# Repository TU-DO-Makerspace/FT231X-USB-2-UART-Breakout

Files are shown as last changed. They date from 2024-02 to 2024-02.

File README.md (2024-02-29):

# FT231X USB 2 UART Breakout

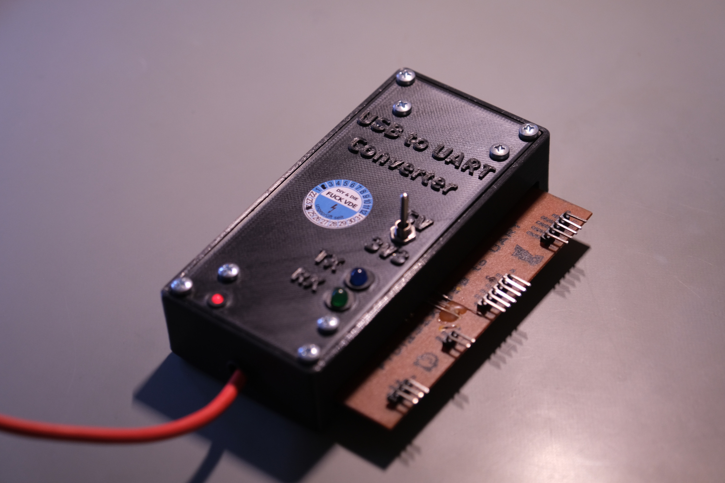
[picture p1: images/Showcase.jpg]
Showcase


This repository features a USB 2 UART converter/breakout board built on the FTDI FT231X IC. Although numerous affordable USB to UART converters are readily available on the market, this particular one was designed around a spare FT231X IC soldered to a SMD break-out adapter we had in our lab. Figured we'd make use of it then! The PCB was designed with a single-board layout in consideration, as we etched the PCB oursevles.

We don't really expect anyone to use this design, but we're making it available for archival purposes in case it breaks down some day or someone is simply curious about the design. However, if you do happen to find it useful, that's pretty awesome too!

## Schematic

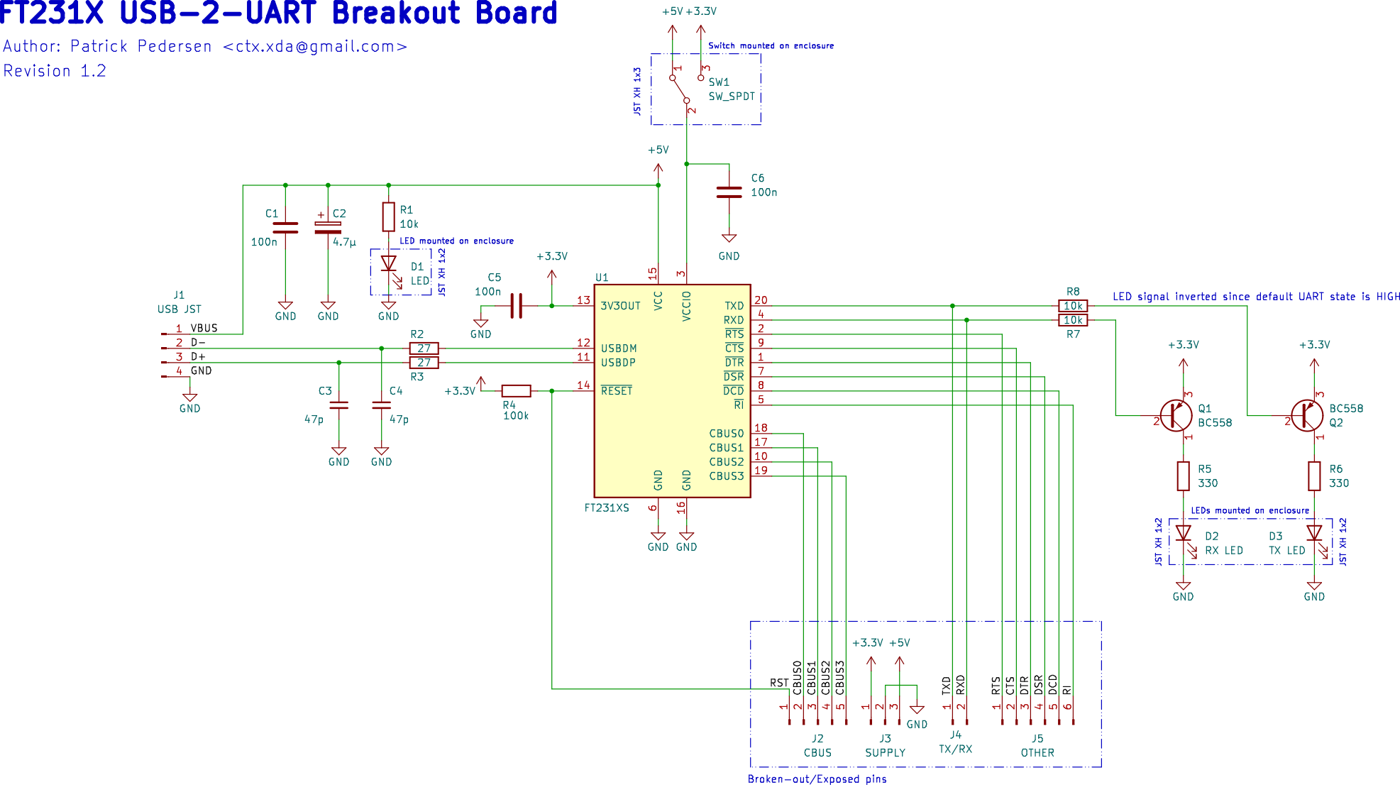
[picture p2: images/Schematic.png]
Schematic


The schematic pretty much provides the bare minimum to use the FT231X IC as a USB to UART converter. Some notable features include:

- A switch to switch between 3.3V and 5V logic levels
- LEDs to indicate power and data transmission
- Exposed supply, RX, TX, RTS, CTS, DTR, DSR, DCD, and RI pins
- Exposed CBUS pins for custom functionality

The data transmission LEDs have been implemented via the RX/TX lines. While it is possible to use the CBUS pins for this purpose, we decided to use the RX/TX lines to keep all CBUS pins exposed.

The schematic KiCAD file can be found in the `kicad` directory.

## PCB

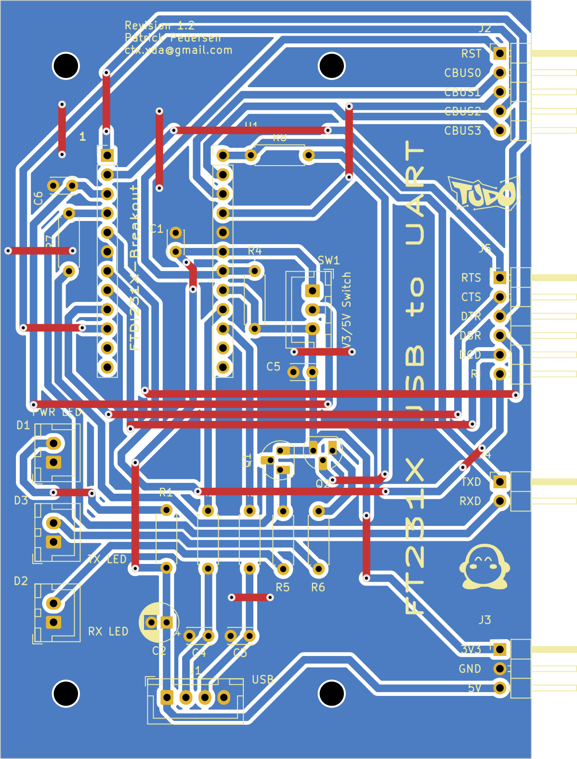
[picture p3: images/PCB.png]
PCB


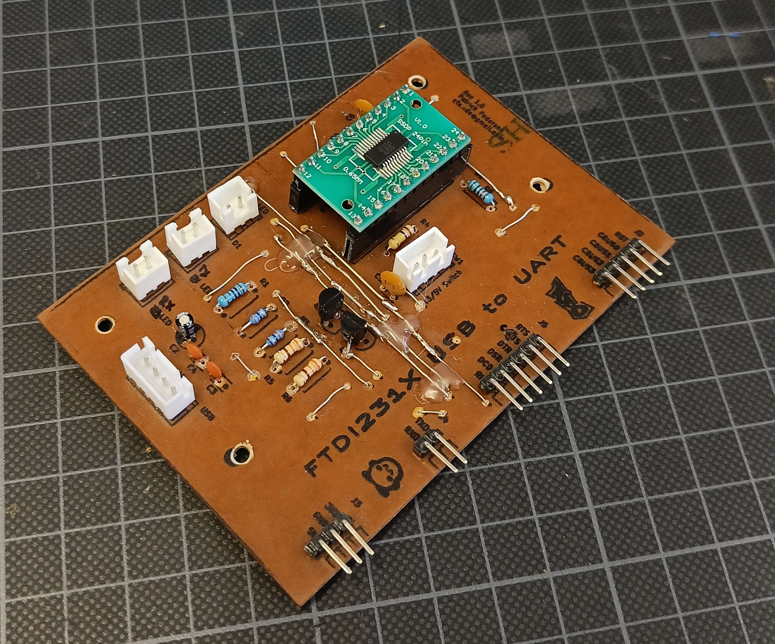
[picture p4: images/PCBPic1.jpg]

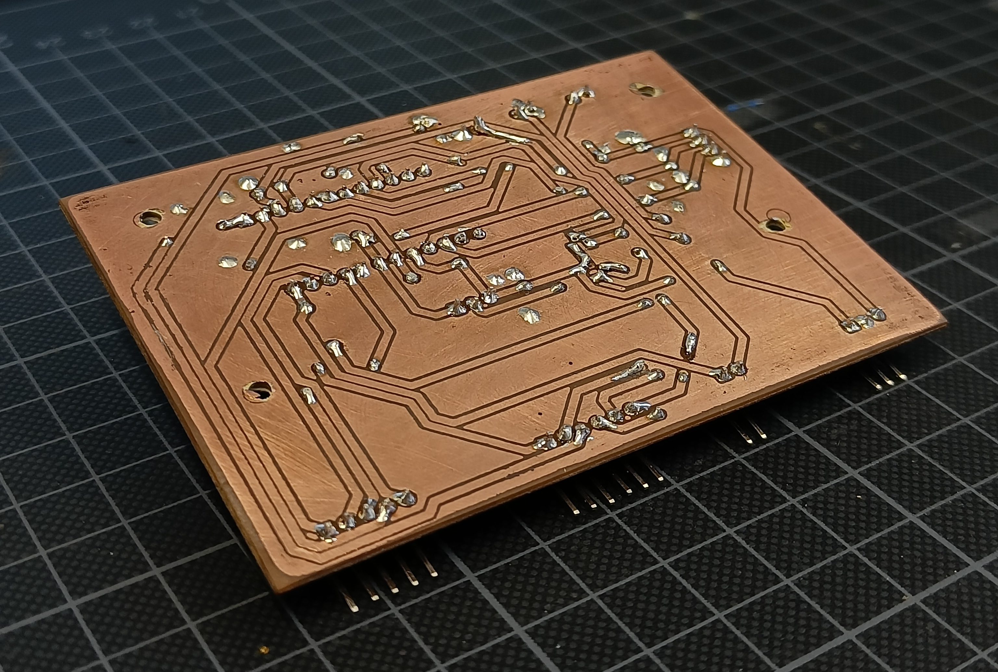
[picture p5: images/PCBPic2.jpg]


The PCB was designed to be self-etched, and as such, it is a single-layer board. The front copper layer is only used to visualize jumpers. We used the "toner transfer method" to etch the PCB, which allows us to print a silk screen on to the non-conductive layer.

The PCB was designed in a way where the right side of the board breaks out the FT231X pins with angled 2.54mm male headers. The side of the board is then meant to "stick out" of the enclosure to allow for easy access to the pins. We also make heavy use of JST connectors so that the board can easily be removed from the enclosure and repaired or modified if necessary. The front silk-screen indicates the pinout of the FT231X IC, as well as the pinout of the JST connectors. This was done to make it easier to use the board without having to refer to the schematic.

The PCB KiCAD file can be found in the `kicad` directory.

## Enclosure

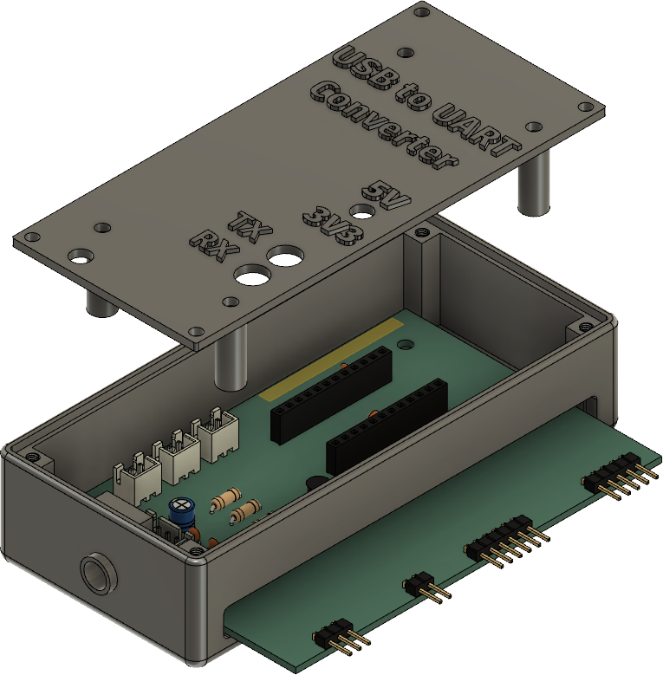
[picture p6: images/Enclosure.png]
Enclosure


The enclosure was designed for 3D printing, intended to house most of the PCB, while leaving the right side of the board exposed for easy access to the break-out pins. This design choice also allows the silk-screen to be utilized for identifying the functionality of the break-out pins.

The 3mf files for the enclosure can be found in the `enclosure` directory.

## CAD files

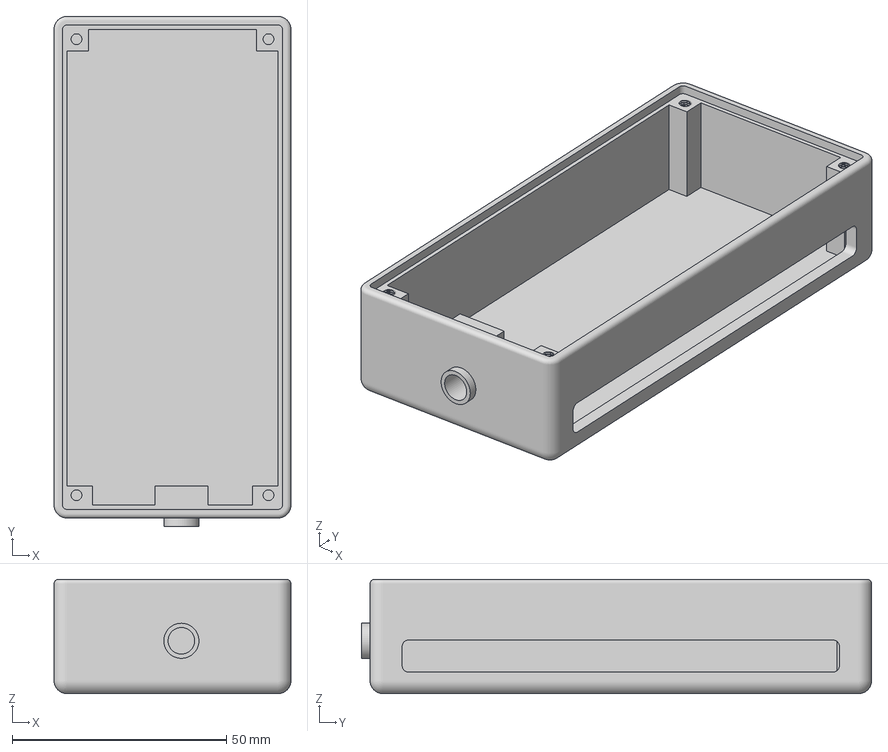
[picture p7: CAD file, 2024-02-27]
enclosure/USB2UART_Bottom.3mf
55.3 x 119.0 x 26.6 mm

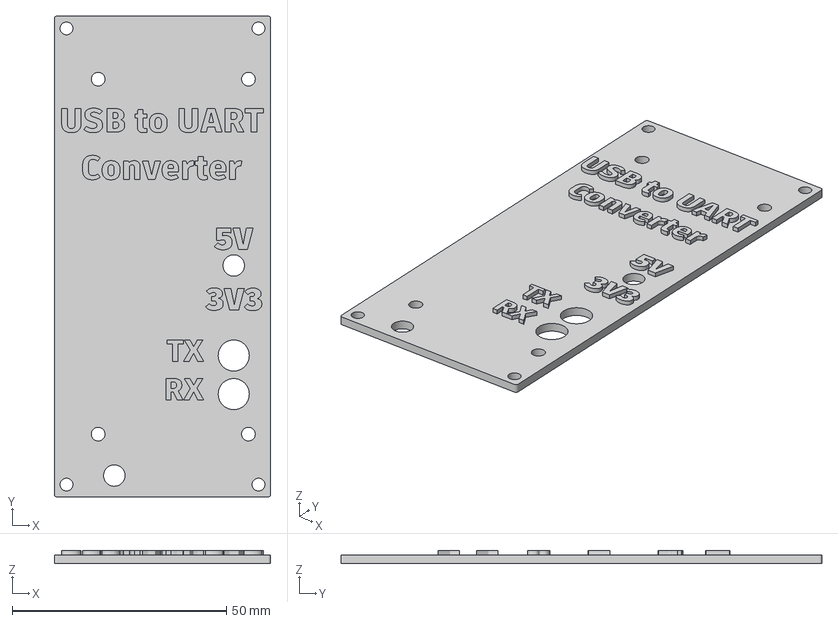
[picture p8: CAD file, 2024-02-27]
enclosure/USB2UART_Lid.3mf
50.5 x 112.2 x 3.00 mm

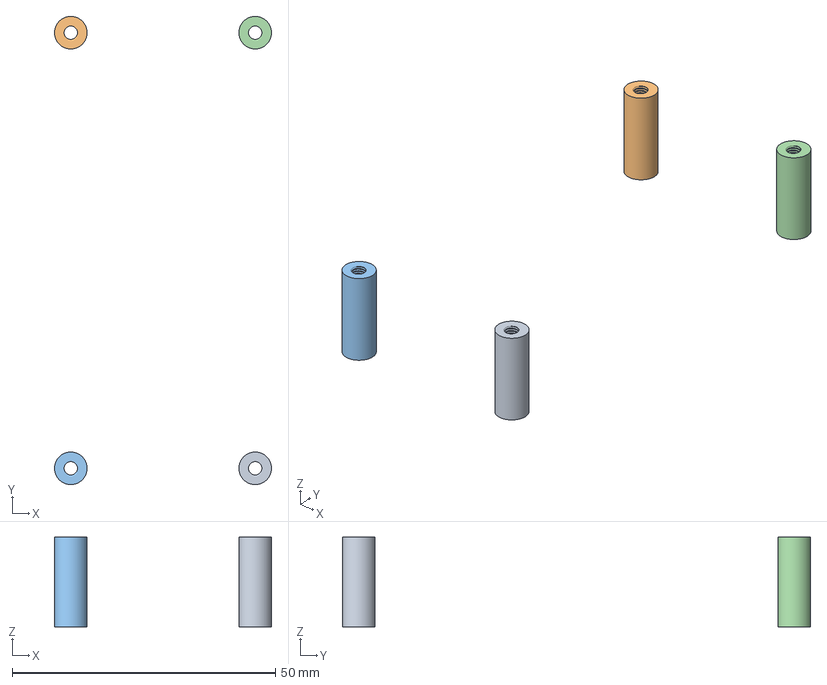
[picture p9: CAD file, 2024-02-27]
enclosure/USB2UART_Spacer.3mf
41.3 x 89.0 x 17.0 mm

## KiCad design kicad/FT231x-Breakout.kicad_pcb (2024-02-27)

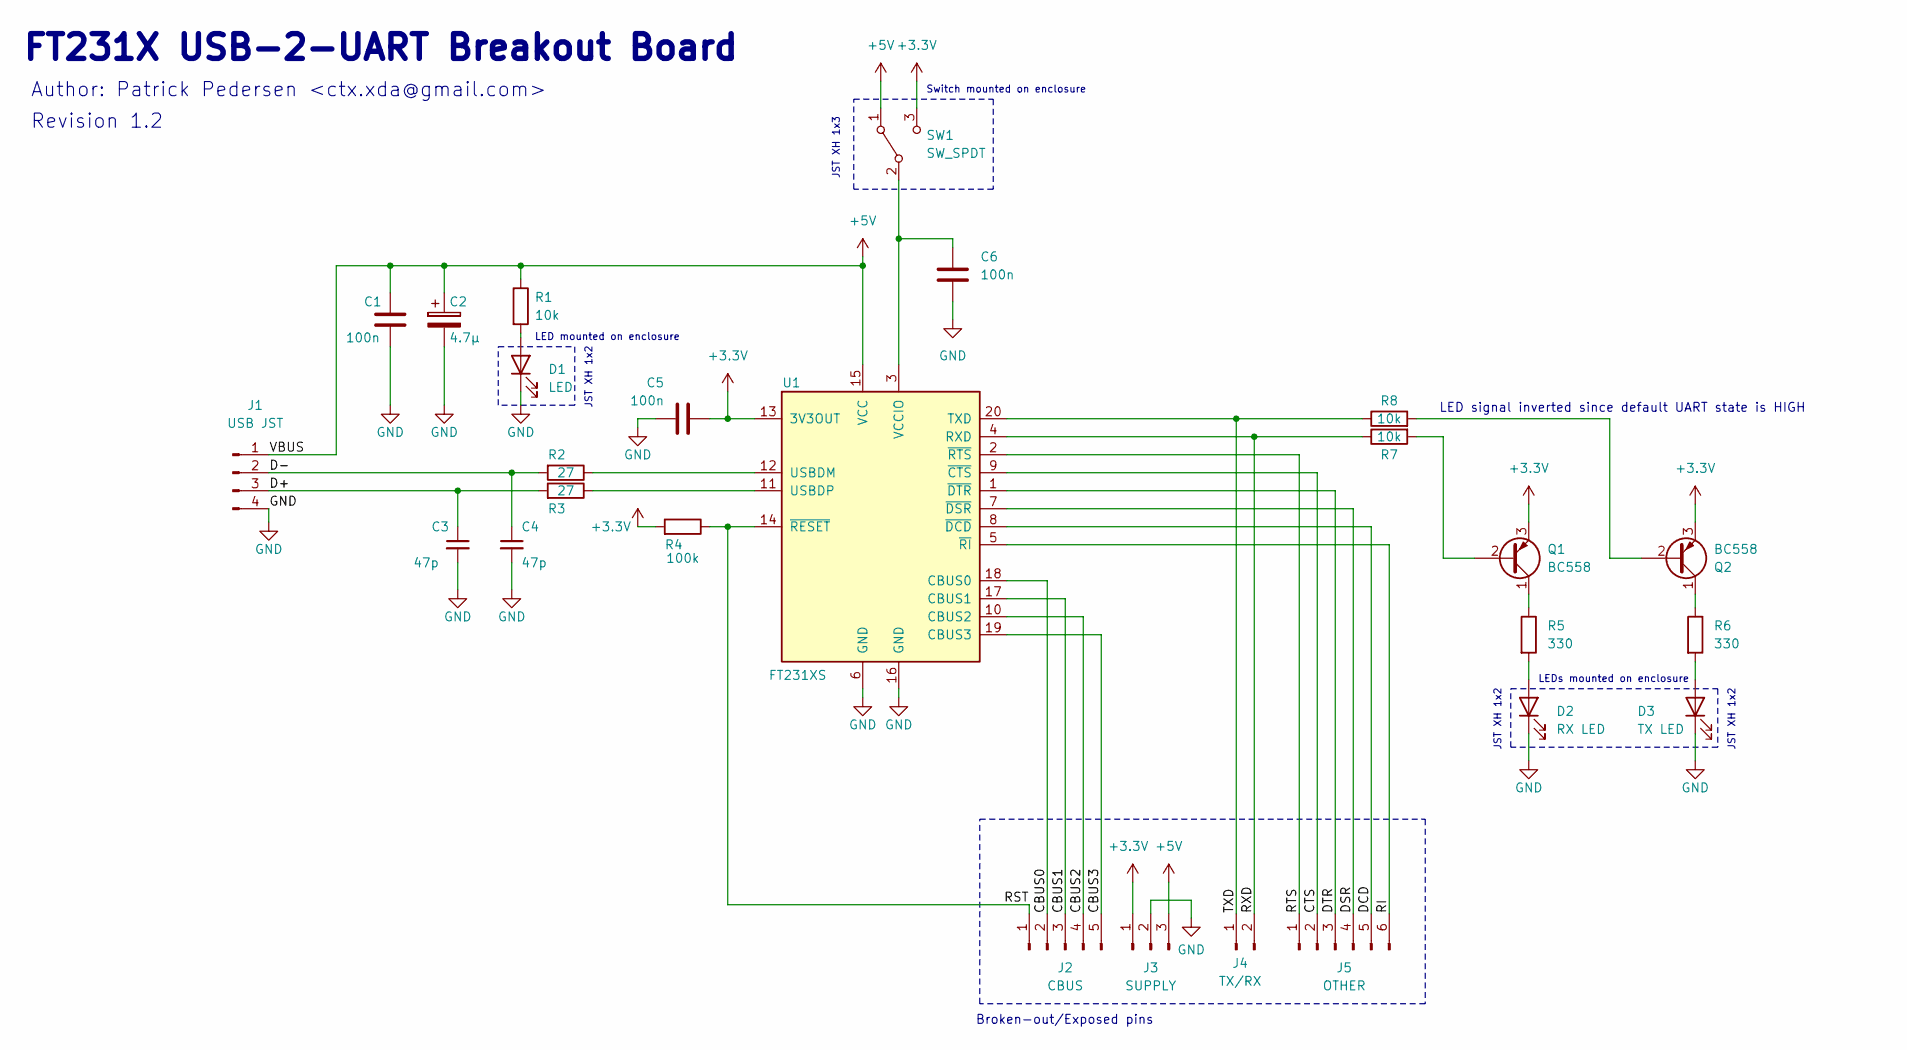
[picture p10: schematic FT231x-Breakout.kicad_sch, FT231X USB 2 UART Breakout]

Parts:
C1, C5, C6: 100n; C_Disc_D3.0mm_W2.0mm_P2.50mm
C2: 4.7µ; CP_Radial_D5.0mm_P2.00mm
C3, C4: 47p; C_Disc_D3.0mm_W2.0mm_P2.50mm
D1: LED; JST_XH_B2B-XH-A_1x02_P2.50mm_Vertical
D2: RX LED; JST_XH_B2B-XH-A_1x02_P2.50mm_Vertical
D3: TX LED; JST_XH_B2B-XH-A_1x02_P2.50mm_Vertical
J1: USB JST; JST_XH_B4B-XH-A_1x04_P2.50mm_Vertical
J2: CBUS; PinHeader_1x05_P2.54mm_Horizontal
J3: SUPPLY; PinHeader_1x03_P2.54mm_Horizontal
J4: TX/RX; PinHeader_1x02_P2.54mm_Horizontal
J5: OTHER; PinHeader_1x06_P2.54mm_Horizontal
Q1, Q2: BC558; TO-92_HandSolder
R1, R7, R8: 10k; R_Axial_DIN0207_L6.3mm_D2.5mm_P7.62mm_Horizontal
R2, R3: 27; R_Axial_DIN0207_L6.3mm_D2.5mm_P7.62mm_Horizontal
R4: 100k; R_Axial_DIN0207_L6.3mm_D2.5mm_P7.62mm_Horizontal
R5, R6: 330; R_Axial_DIN0207_L6.3mm_D2.5mm_P7.62mm_Horizontal
SW1: SW_SPDT; JST_XH_B3B-XH-A_1x03_P2.50mm_Vertical
U1: FT231XS; FTDI231X_Breakout

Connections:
+3.3V: C5.2, J3.1, Q1.3 (E), Q2.3 (E), R4.2, SW1.3 (C), U1.13 (3V3OUT)
+5V: C1.1, C2.1, J1.1, J3.3, R1.1, SW1.1 (A), U1.15 (VCC)
/CBUS0: J2.2, U1.18 (CBUS0)
/CBUS1: J2.3, U1.17 (CBUS1)
/CBUS2: J2.4, U1.10 (CBUS2)
/CBUS3: J2.5, U1.19 (CBUS3)
/CTS: J5.2, U1.9 (~CTS)
/D+: C3.1, J1.3, R3.2
/D-: C4.1, J1.2, R2.2
/DCD: J5.5, U1.8 (~DCD)
/DSR: J5.4, U1.7 (~DSR)
/DTR: J5.3, U1.1 (~DTR)
/RI: J5.6, U1.5 (~RI)
/RST: J2.1, R4.1, U1.14 (~RESET)
/RTS: J5.1, U1.2 (~RTS)
/RXD: J4.2, R7.1, U1.4 (RXD)
/TXD: J4.1, R8.1, U1.20 (TXD)
GND: C1.2, C2.2, C3.2, C4.2, C5.1, C6.2, D1.1 (K), D2.1 (K), D3.1 (K), J1.4, J3.2, U1.6 (GND), U1.16 (GND)
unnamed: D1.2 (A), R1.2
unnamed: D2.2 (A), R5.2
unnamed: D3.2 (A), R6.2
unnamed: Q1.2 (B), R7.2
unnamed: Q1.1 (C), R5.1
unnamed: Q2.2 (B), R8.2
unnamed: Q2.1 (C), R6.1
unnamed: C6.1, SW1.2 (B), U1.3 (VCCIO)
unnamed: R2.1, U1.12 (USBDM)
unnamed: R3.1, U1.11 (USBDP)

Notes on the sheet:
FT231X USB-2-UART Breakout Board
JST XH 1x2
Broken-out/Exposed pins
LED mounted on enclosure
LED signal inverted since default UART state is HIGH
JST XH 1x3
Switch mounted on enclosure
LEDs mounted on enclosure
Revision 1.2
Author: Patrick Pedersen <ctx.xda@gmail.com>

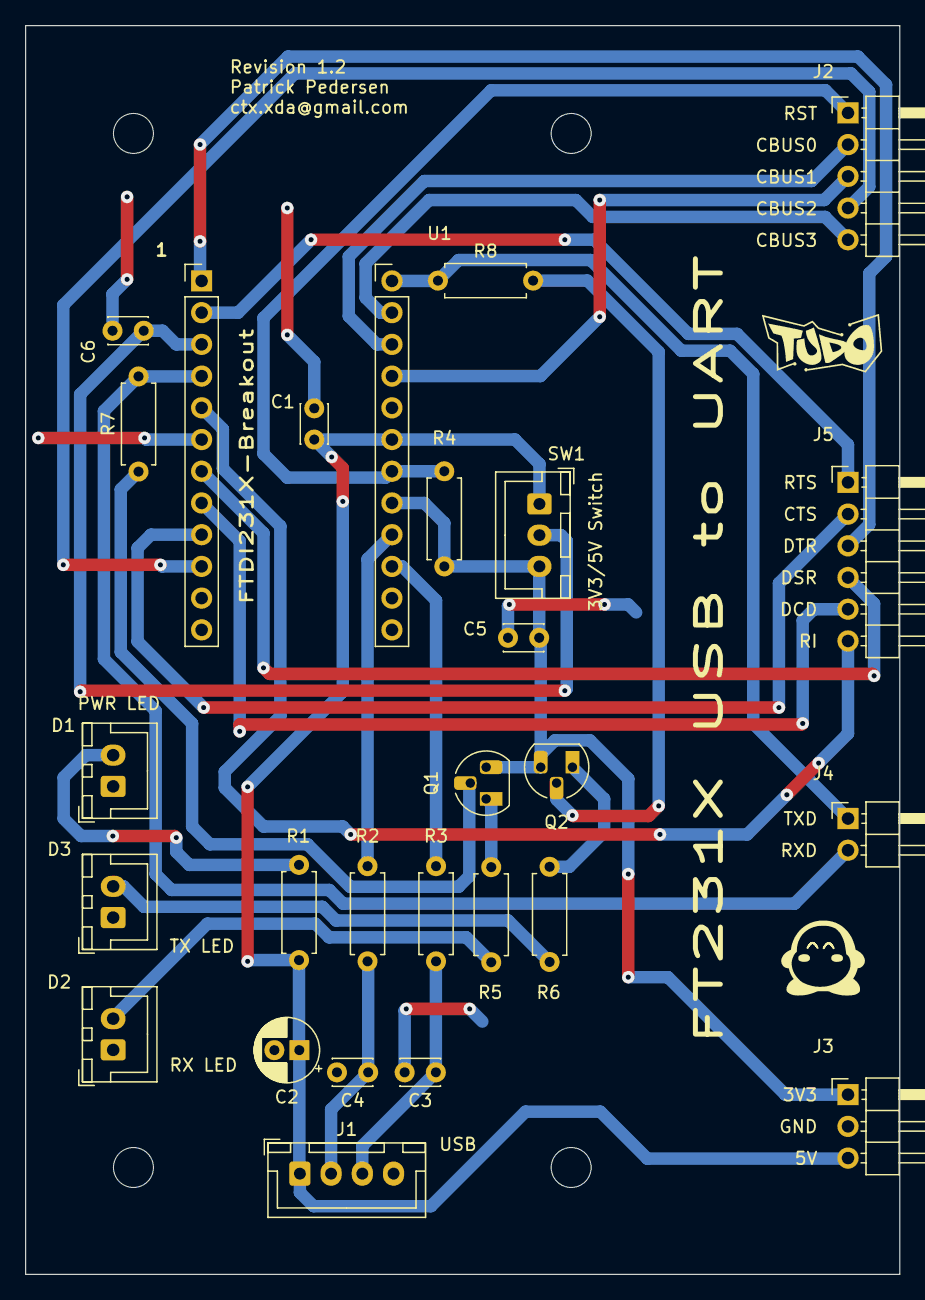
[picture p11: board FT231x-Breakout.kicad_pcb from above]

Board: 2 copper layers, 70.0 x 100.0 mm, 26 parts (0 on the bottom side), 28 nets.

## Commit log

2024-02-06 Initial commit of Rev 1.0 (with fixed Labels)
    [FTDIBreakout.kicad_pcb, FTDIBreakout.kicad_sch]
2024-02-27 Rev 1.2 + Added README
    [FT231x-Breakout.kicad_pcb, FT231x-Breakout.kicad_sch]
2024-02-27 Added enclosure files
    [FT231x-Breakout.kicad_pcb, FT231x-Breakout.kicad_sch, USB2UART_Bottom.3mf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]
2024-02-27 Kicad: Moved breakout footprint to kicad dir

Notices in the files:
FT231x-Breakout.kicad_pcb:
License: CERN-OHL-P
